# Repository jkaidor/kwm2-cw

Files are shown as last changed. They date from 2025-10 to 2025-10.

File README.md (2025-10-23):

# kwm2-cw
CW support in the Collins KWM-2 was not good.  In order to transmit code, they used an audio oscillator inputting into the SSB transmit chain.  To make this work, they used a high injection frequency - in my radio, 1750Hz.  So the user hears 1750 Hz as the sidetone, and also must listen to their QSO partner at 1750 Hz.  Very high and squeaky.  A comfortable 600hz would have landed its second harmonic inside the bandpass of the mechanical filter.
My card fixes this by translating the 1750Hz ( either sidetone or other signal, doesn't matter ) to 650Hz.  It does so by first bandpass filtering the 1750Hz.  Then mixing it down to 650Hz with an 1100Hz oscillator.  Then a high pass filter to chop off the unwanted image frequency.  The card does this all in *software*.  It has a PJRC Teensy 4.1 processor card, and I used the PJRC audio library to implement it.
This depository includes the KiCAD files, the gerbers, and the Arduino sketch.
The card mounts to the back of the KWM-2 PTO.  There's a couple of convenient studs sticking out of it.
In my implementation, I built a power supply mounted on a tube plug, plugged into the noise blanker socket.
I also made room for a BHI noise reduction module.  So now, when I set my KWM-2 to noise blanker mode, I get DSP noise reduction.  Actual noise blankers don't do much nowadays;  The Woodpecker is long gone, and I don't operate mobile with my boatanchors.
The CW fixer also supports two bandwidths - wide and narrow.  When you select CW from the mode switch, you get one of those bandwidths.  Select it again, and you get the other one.
There is an unused lug on the mode switch that gives a ground in CW mode - very convenient!

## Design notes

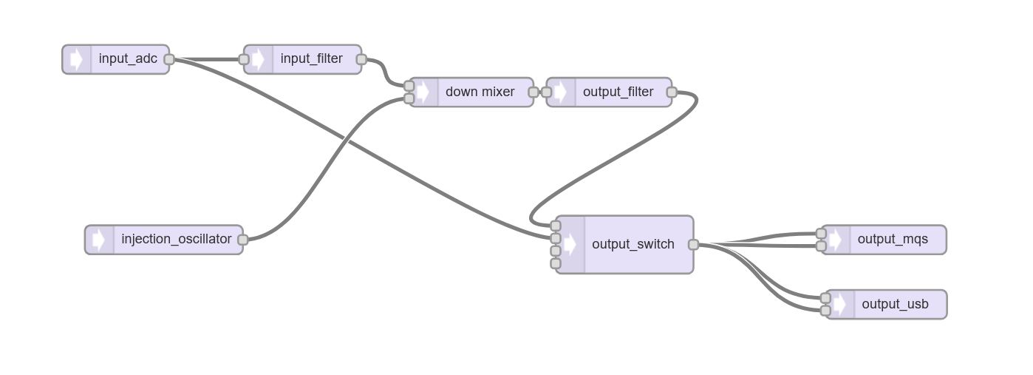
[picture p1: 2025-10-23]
Capture.JPG

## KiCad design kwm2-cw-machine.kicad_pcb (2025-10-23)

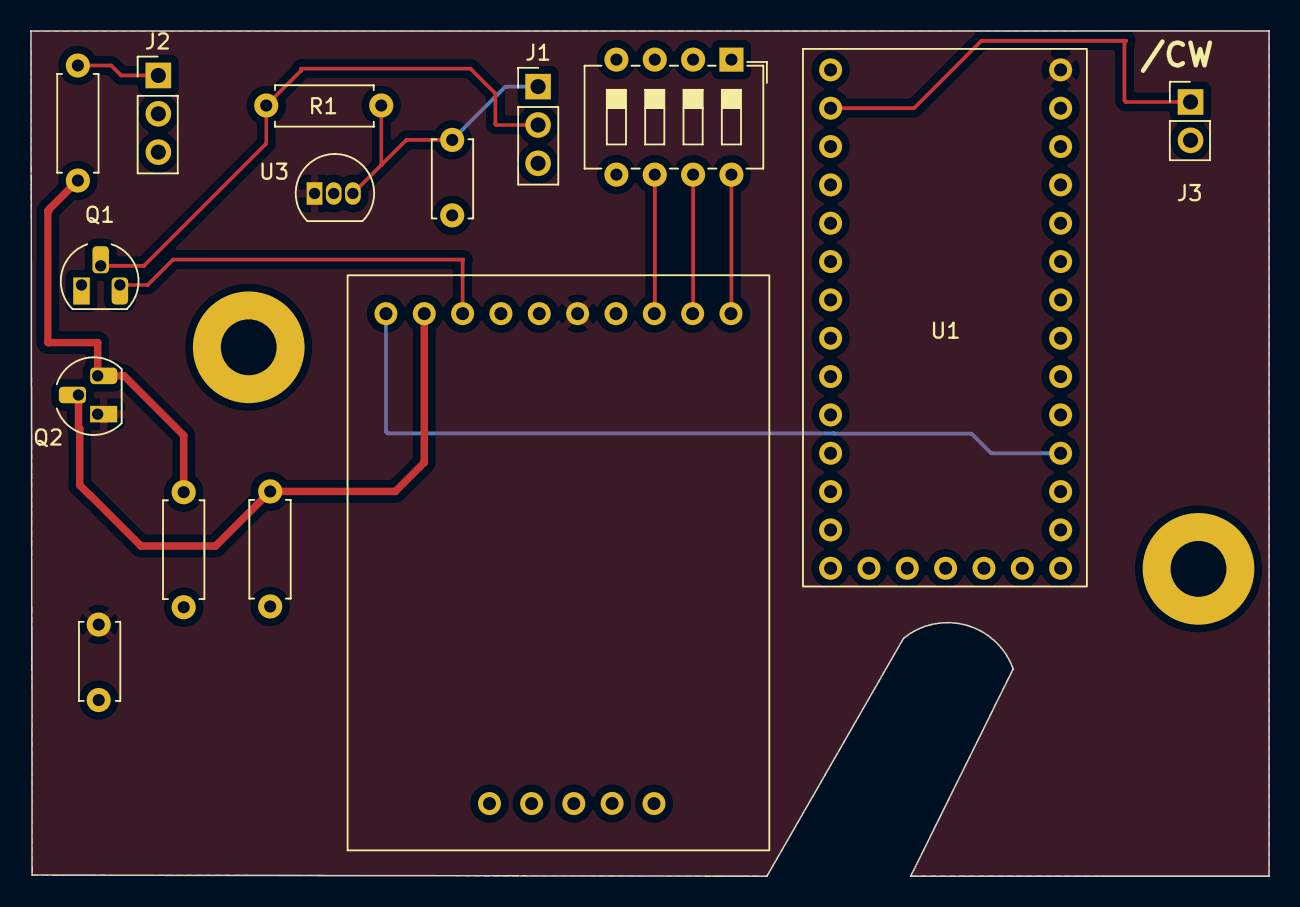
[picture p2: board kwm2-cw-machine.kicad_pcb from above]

Board: 2 copper layers, 82.0 x 56.0 mm, 15 parts (0 on the bottom side), 13 nets.

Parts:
C1, C2: C; C_Disc_D5.0mm_W2.5mm_P5.00mm
J1: To NB Socket; PinHeader_1x03_P2.54mm_Vertical
J2: To Audio; PinHeader_1x03_P2.54mm_Vertical
J3: Conn_01x02_Pin; PinHeader_1x02_P2.54mm_Vertical
Q1: 2N3904; TO-92_HandSolder
Q2: Q_NJFET_DSG; TO-92_HandSolder
R1, R2, R3, R4: R_US; R_Axial_DIN0207_L6.3mm_D2.5mm_P7.62mm_Horizontal
SW1: SW_DIP_x04; SW_DIP_SPSTx04_Slide_6.7x11.72mm_W7.62mm_P2.54mm_LowProfile
U1: Teensy4.0; Teensy 4.0
U2: BHI 1901-PCB
U3: L78L05; TO-92_Inline

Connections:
+5V: C1.1, Q2.1 (D), U1.33 (VIN), U2.5 (V+), U3.1 (VO)
+9V: C2.1, J1.1, R1.1, U3.3 (VI)
GND: C1.2, C2.2, J1.3, J2.2, J3.2, Q1.1 (E), R2.2, R4.2, SW1.1, SW1.2, SW1.3, U1.1 (GND), U1.17 (GND), U1.32 (GND), U2.7 (GND), U3.2 (GND)
unnamed: J1.2, Q1.2 (B), R1.2
unnamed: J2.1, R3.1
unnamed: J3.1, U1.2 (0_RX1_CRX2_CS1)
unnamed: Q1.3 (C), U2.8 (Noise_Reduction_Off)
unnamed: Q2.3 (G), R2.1, R3.2
unnamed: Q2.2 (S), R4.1, U2.9 (Audio_In)
unnamed: U1.23 (16_A2_RX4_SCL1), U2.10 (Audio_Output)
unnamed: SW1.8, U2.1 (Reduction_Bit_0)
unnamed: SW1.7, U2.2 (Reduction_Bit_1)
unnamed: SW1.6, U2.3 (Reduction_bit_2)

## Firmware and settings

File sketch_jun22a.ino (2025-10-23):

#include <Audio.h>
#include <Wire.h>
#include <SPI.h>
#include <SD.h>
#include <SerialFlash.h>
#include <Encoder.h>

#define INPUT_FREQ 1700.0
#define OUTPUT_FREQ  600.0                 //really 600!
#define OUTPUT_LOWPASS 800.0
#define INJECTION_FREQ (INPUT_FREQ-OUTPUT_FREQ)
//#define INPUT_FILTER_Q 0.707
#define INPUT_FILTER_Q   10.0
#define OUTPUT_FILTER_Q  10.0 //0.707
#define CW_ENABLE_PIN 0
bool cw_enabled;
#define CW_OUTPUT_PORT 0
#define SSB_OUTPUT_PORT 1
#define ZERO_GAIN 0.0f
#define UNITY_GAIN 1.0f

// Is this an external box, or a card INSIDE the KWM-2?
#define INTERNAL_CARD
AudioOutputUSB           output_usb;           //
AudioInputAnalog         input_adc;
AudioSynthWaveformSine   injection_oscillator;          //xy=124.00001525878906,327.0333251953125
AudioFilterBiquad        input_filter;        //xy=270.0333251953125,193.03333282470703
AudioEffectMultiply      modulator;      //xy=445.0333251953125,227.0333251953125
AudioFilterBiquad        output_filter;        //xy=588.0333251953125,227.0333251953125
AudioMixer4              output_switch;         //xy=604.0333404541016,385.03334045410156
AudioOutputMQS           output_mqs;           //xy=609.0333251953125,472.0333251953125


int input_filter_q = INPUT_FILTER_Q;

// GUItool: begin automatically generated code
//AudioInputAnalog         input_adc;           //xy=75.03334045410156,192.0333251953125
AudioSynthToneSweep test_oscillator;

AudioConnection          patchCord1(input_adc, input_filter);
AudioConnection          patchCord2(input_adc, 0, output_switch, 1);
AudioConnection          patchCord3(injection_oscillator, 0, modulator, 1);
AudioConnection          patchCord4(input_filter, 0, modulator, 0);
AudioConnection          patchCord5(modulator, output_filter);
AudioConnection          patchCord6(output_filter, 0, output_switch, 0);
AudioConnection          patchCord7(output_switch, 0, output_mqs, 0);
AudioConnection          patchCord8(output_switch, 0, output_mqs, 1);
//AudioConnection          patchCord9(output_switch, 0, output_usb, 0);
//AudioConnection          patchCord10(output_switch, 0, output_usb, 1);

#define NUM_SELECTIVITIES 23

#ifdef INTERNAL_CARD
unsigned long cw_input_debounce_delay = 50;
bool raw_cw_input;
unsigned long cw_input_changed_time;
bool cw_input = false;         //don't really know what it is... but don't want it random.
bool last_cw_input = false;
#endif


//Actually "Q" values to set up the input bandpass filter.
float selectivities[ NUM_SELECTIVITIES ]
  = {
     0.5,
     0.6,
     0.7,
     0.8,
     0.9,
     1.0,
    2.0,
    3.0,
    4.0,
    5.0,
    6.0,
    7.0,
    8.0,
    9.0,
    10.0,
    15.0,
    20.0,
    25.0,
    30.0,
    35.0,
    40.0,
    45.0,
    50.0
    };

int selectivity_index = 0;


Encoder selectivity_encoder( 34, 33 );

#ifndef INTERNAL_CARD
void set_raw_selectivity( long );
int32_t raw_selectivity = 0L;
int32_t new_raw_selectivity = 0L;
#endif  //! INTERNAL_CARD

uint32_t when_changed;

void setup()
  {
  Serial.begin( 115200L );
  pinMode( CW_ENABLE_PIN, INPUT_PULLUP );
  AudioMemory( 16 );
  set_input_q( input_filter_q );

  output_filter.setLowpass( 0, OUTPUT_LOWPASS, OUTPUT_FILTER_Q );
  output_filter.setLowpass( 0, OUTPUT_LOWPASS, OUTPUT_FILTER_Q );
  output_filter.setLowpass( 0, OUTPUT_LOWPASS, OUTPUT_FILTER_Q );
  output_filter.setLowpass( 0, OUTPUT_LOWPASS, OUTPUT_FILTER_Q );

  injection_oscillator.frequency( INJECTION_FREQ );
  injection_oscillator.amplitude( 1.0f );

  pinMode( 32, INPUT_PULLUP );
  pinMode( 33, INPUT_PULLUP );
  selectivity_encoder.write( 0 );
  disable_cw();
  cw_enabled = false;
  cw_input_changed_time = millis();

  }

void loop()
  {
  // Debounce the CW enable input.  We do this by not accepting a change unless it has
  // been stable for a certain amount of time.
  raw_cw_input = digitalRead( CW_ENABLE_PIN );

  if( raw_cw_input != last_cw_input )
    {
    // It's changed!
    last_cw_input = raw_cw_input;
    cw_input_changed_time = millis();
    }
  // Subsequent swings after the initial change don't hit the above.
  if(( millis() - cw_input_changed_time ) > 10 )
    {
    cw_input = raw_cw_input;
    }

  if( !cw_input )
    {
    // The rig is in CW mode.
    if( !cw_enabled )
      {
      Serial.print( "Enabling CW mode\n");
      enable_cw();
      cw_enabled = true;
      // Toggle selectivity
      change_input_q();
      }
    }
  else
    {
    // The CW enable pin says "not CW"

    if( cw_enabled )
      {
      Serial.print( "Disabling CW mode\n");
      disable_cw();
      cw_enabled = false;
      }
    }

  //if( !test_oscillator.isPlaying() )    test_oscillator.play( 0.5, 1720, 1780, 1 );
  #ifndef INTERNAL_CARD
  uint32_t now = millis();
  new_raw_selectivity = selectivity_encoder.read();
  if( new_raw_selectivity != raw_selectivity )
    {
    if( now > (when_changed+100))
      {      
      set_raw_selectivity( new_raw_selectivity, raw_selectivity );
      raw_selectivity = new_raw_selectivity;
      when_changed = now;
      }
    }
  #endif //! INTERNAL_CARD
  }

#ifndef INTERNAL_CARD
void set_raw_selectivity( int32_t new_raw_selectivity, int32_t old_raw_selectivity )
  {
  if( new_raw_selectivity == old_raw_selectivity ) return;
  Serial.printf( "New raw selectivity is %d, old raw selectivity is %d\n", new_raw_selectivity, old_raw_selectivity );
  if( new_raw_selectivity < old_raw_selectivity )
    {
    selectivity_index--;
    // Don't let it decrement forever...
    if( selectivity_index < 0) selectivity_index = 0;
    }
  else
    {
    // raw selectivity is bigger
    selectivity_index++;
    // Don't let it increment forever
    if( selectivity_index >= NUM_SELECTIVITIES)
      {
      selectivity_index = NUM_SELECTIVITIES-1 ;
      }
    }
  Serial.printf( "   Setting selectivity index %d, filter Q %f\n", selectivity_index, selectivities[ selectivity_index ]);
  set_input_q( selectivities[ selectivity_index ] );
  }
#endif //! INTERNAL_CARD

void enable_cw()
  {
  // We use two inputs on the output switch.  input 0 goes to the output CW filter.  Input 1 goes to the input ADC for
  // undisturbed audio
  output_switch.gain( CW_OUTPUT_PORT, UNITY_GAIN );
  output_switch.gain( SSB_OUTPUT_PORT, ZERO_GAIN );
  }

void disable_cw()
  {
  output_switch.gain( CW_OUTPUT_PORT, ZERO_GAIN );
  output_switch.gain( SSB_OUTPUT_PORT, UNITY_GAIN );
  }

void set_input_q( float Q )
  {
  input_filter.setBandpass( 0, INPUT_FREQ, Q );  
  input_filter.setBandpass( 1, INPUT_FREQ, Q ); 
  input_filter.setBandpass( 2, INPUT_FREQ, Q );  
  input_filter.setBandpass( 3, INPUT_FREQ, Q );    
  }

//Each time CW is enabled, we will choose a different Q
// ...because we don't have any more controls in the KWM2
void change_input_q()
  {
    if( input_filter_q == 10.0 )  //tight
      {
      input_filter_q = 1.0;        //loose  
      }
    else
      {
      input_filter_q = 10.0;
      }
    set_input_q( input_filter_q );
  }
